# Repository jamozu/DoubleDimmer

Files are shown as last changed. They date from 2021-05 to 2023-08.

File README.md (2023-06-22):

# Introduction
This DIY project is quite involved, so first, why go this route?

There are essentially two ways to control the lights at home, Smart Bulbs or with Smart Light Switches / dimmers, both with advantages and disadvantages. 

Smart Light Switches are cheaper. Purely based on cost, smart light switches are likely to be far cheaper than smart bulbs, especially since one light switch can control multiple light fixtures, depending on how your house’s wiring is set up.

You can use any bulb with Smart Light Switches. Since the traditional light bulb industry is very mature, the range of styles and accessories is still much broader.
Smart Light Switches can control your existing fixtures without complex modifications.

The main disadvantage is that special wiring is required in the electric boxes where the switches are to be installed (the wires for hot, neutral, as well as the wire for the light are required, although there are already some options that do not require both cables, this project has not reached the point of having a single wire power supply). In most recent installations, this is not an issue, but it can be a problem for older installations; also, there are different standards in each country.

While smart bulbs offer more flexibility and have the possibility of adding color, they are more expensive and the need for this level of control, from my point of view, only makes sense in a few specific areas and in the end, you can combine the two solutions.

For these reasons, I leaned towards Smart Light Switches for the bulk of my lights.

Now since there are several options on the market, why go the DIY path?

Mainly I return to the point of the range of styles and accessories. In the arena of traditional light switches, there are thousands of colors, styles, textures and accessory options that are not yet available in smart switches. I started this project a few years ago when smart devices were a lot more expensive.

On the other hand, inexpensive smart switches do not offer enough functionality, and some of the more expensive ones did not fit the form factor of my installation. 

By taking the DIY path, I can get the flexibility in style, form factor, and functionality at a reasonable cost.

With that out of the way, let’s go to the project itself.

# IoT Double Dimmer

This project consists of an AC light dimmer for one or two incandescent light bulbs or dimmable LED bulbs, with mains AC voltage of 110 to 220 V, 50 or 60Hz, up to 400W, using the WiFi enabled microcontroller ESP-12E / F.

The Dimmer functionality is achieved using the phase control method, using a TRIAC for each bulb, varying the total power applied. This method works very well with incandescent light bulbs and with LED lamps that have the Dimmable specification.

Features:
* Lights can be dimmed from 5% to 100% power.
* The minimum power is configurable for different types of bulbs and environments.
*	Supports transitions between brightness levels.
*	One push button per light bulb to control the ON/OFF state and brightness.
*	A LED indicator for each button/light bulb.
*	LED indicators change intensity if light is ON or OFF. 
*	LED indicators intensity can be set remotely or turned off for day / night mode.
*	Smart control and configuration using MQTT over WiFi; An MQTT broker is required.
*	ON/OFF state and brightness can be set via the push buttons or remotely via WiFi/MQTT.
*	Integrated into Home-Assistant or other MQTT compatible IoT Hubs, with auto discovery.
*	Setup Portal over WiFi, to configure WiFi/MQTT parameters.
*	The Setup Portal is started by a double reset or optionally with multi-click of any of the light buttons.
*	On Power Up the device resets to the last known state, using MQTT retain or EEPROM.
*	Optional double and triple clicks to trigger additional actions.
*	Advanced configuration through MQTT.
*	Each light can be set to "Switch Mode" in case the Dimmer functionality is not required or supported in a specific bulb.
*	The Dimmer auto detects AC frequency.

For mor details check the documentation at: https://github.com/jamozu/DoubleDimmer/blob/main/RRoble_Double_Dimmer.pdf

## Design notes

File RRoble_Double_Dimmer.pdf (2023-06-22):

# RRoble Double Dimmer

## Single and Double Dimmer with IoT over WiFi

Revision History
Version date | Author | Change Summary
Tuesday, June 25, 2019 | Jesus Amozurrutia | First Draft
Saturday, November 07, 2020Jesus Amozurrutia | | Version 1
Friday, April 30, 2021 | Jesus Amozurrutia | Version 2
Monday, November 01, 2021 Jesus Amozurrutia | | Version 3
Tuesday, January 31, 2023 | Jesus Amozurrutia | Version 4
Thursday, June 22, 2023 | Jesus Amozurrutia | Version 5

Confidential | Page 2

Contents

## 1. Introduction

This DIY project is quite involved, so first, why go this route?
There are essentially two ways to control the lights at home, Smart Bulbs or with Smart Light Switches / dimmers, both with advantages and disadvantages.
Smart Light Switches are cheaper. Purely based on cost, smart light switches are likely to be far cheaper than smart bulbs, especially since one light switch can control multiple light fixtures, depending on how your house’s wiring is set up.
You can use any bulb with Smart Light Switches. Since the traditional light bulb industry is very mature, the range of styles and accessories is much broader. In recent years, new smart lights solutions have appeared that allow for flexibility and different styles, but for the bulk of the lights it is a home or office, the Smart Switch is still the best option.
Smart Light Switches can control your existing fixtures without complex modifications.
The main disadvantage is that special wiring is required in the electric boxes where the switches are to be installed (the wires for hot, neutral, as well as the wire for the light are required, although there are already some options that do not require both cables, this project has not reached the point of having a single wire power supply). In most recent installations, this is not an issue, but it can be a problem for older installations; also, there are different standards in each country.
While smart bulbs offer more flexibility and have the possibility of adding color, they are more expensive and the need for this level of control, from my point of view, only makes sense in a few specific areas and in the end, you can combine the two solutions.
For these reasons, I leaned towards Smart Light Switches for the bulk of my lights.
Now since there are several options on the market, why go the DIY path?
Mainly I return to the point of the range of styles and accessories. In the arena of traditional light switches, there are thousands of colors, styles, textures and accessory options that are not yet available in smart switches. I started this project a few years ago when smart devices were a lot more expensive.
On the other hand, inexpensive smart switches do not offer enough functionality, and some of the more expensive ones did not fit the form factor of my installation. I have also had the experience that my visitors who are not familiar with devices find some of these devices unintuitive.
By taking the DIY path, I can get the flexibility in style, form factor, and functionality at a reasonable cost.
With that out of the way, let’s go to the project itself.

## 2. IoT Double Dimmer

This project consists of an AC light dimmer for one or two incandescent light bulbs or dimmable LED bulbs, with mains AC voltage of 110 to 220 V, 50 or 60Hz, up to 400W, using the WiFi enabled microcontroller ESP-12E / F.

The Dimmer functionality is achieved with the phase control method, using a TRIAC for each bulb, varying the total power applied. This method works very well with incandescent light bulbs and with LED lamps that have the Dimmable specification.
Features:
- Lights can be dimmed from 5% to 100% power.
- Supports transitions between brightness levels.
- One push button per light bulb to control the ON/OFF state and brightness.
- Single click toggles ON/OFF state.
- Continues press changes brightness.
- A LED indicator for each button/light bulb.
- LED indicators change intensity if light is ON or OFF.
- LED indicators intensity can be set remotely or turned off for day / night mode.
- ON/OFF state and brightness can be set via the push buttons or remotely via WiFi/MQTT.
- Smart control and configuration using MQTT over WiFi; An MQTT broker is required.
- Setup Portal over WiFi, to configure WiFi/MQTT parameters.
- The Setup Portal is started by a double reset or optionally with multi-click of any of the light buttons.
- On Power Up the device resets to the last known state, using MQTT retain or EEPROM.
- Optional double/triple clicks to trigger additional actions.
- Integrated into Home- (https://www.home-assistant.io/)Assistant (https://www.home-assistant.io/) or other MQTT compatible IoT Hubs, with auto discovery.
- Advanced configuration through MQTT.
- Dimming time.
- Default transition speed.
- Minimum power can be set for each light.
- Minimum Turn ON Brightness (some cheap LED bulbs require some a minimum brightness level to actually turn ON).
- Each light can be set to "Switch Mode" in case the Dimmer functionality is not required or supported.
- The Dimmer auto detects AC frequency.

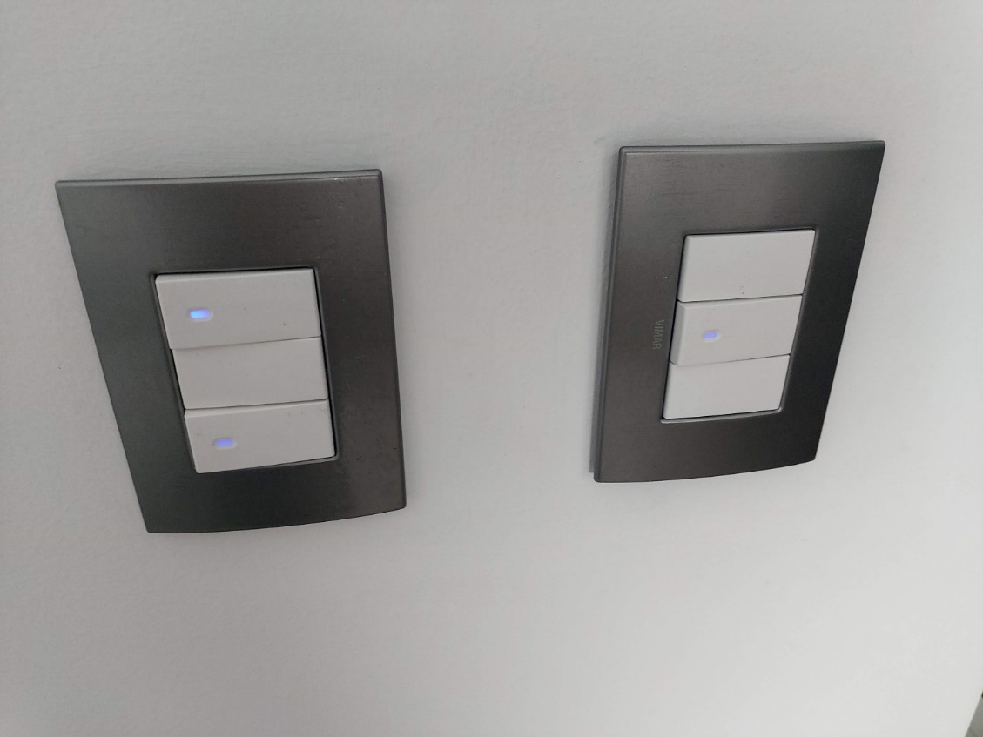
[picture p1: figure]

The finished product.

## 2.1. Definitions

- Device: Refers to the component as a whole. It is used to identify the status and to set the configuration.
- Instance: It refers to each of the lights. The status and configuration of each of the instances can be set individually.
- Brightness: Relative brightness for each of the light bulbs. Brightness is scaled from 1, for minimum brightness, to 100, for maximum brightness.
- Zero Crossing is a pulse that detects every time the AC sinusoidal electrical voltage signal crosses the zero volt zone. It is used to synchronize the phase control.
- Power: The electrical power applied to the light bulb to achieve the desired brightness. Power is regulated using phase control, by varying the time to trigger the TRIAC after the zero crossing detection. The applied power is linear and proportional to the brightness value.
- Minimum Power: The minimum power applied to the light bulb when the brightness has a value of 1. The default value is 5% and it can be configured to any value between 4% and 50%.
- Duty Cycle: The time that the TRIAC is ON in relation to the duration of the AC power signal period.
- OTA: Over The Air updates. Allow the firmware to be updated over WiFi.

## 3. Hardware

The hardware is based on an ESP-12E/F micro controller, using TRIACs to control the power applied to the light bulbs. The controller board is mounted over some Vimar® wall switches. I choose this particular brand because it features a wide range of styles and colors for the decorative plates and buttons. Finally, a 3D printed cover to protect the circuit.
The parts I am using from Vimar® are:

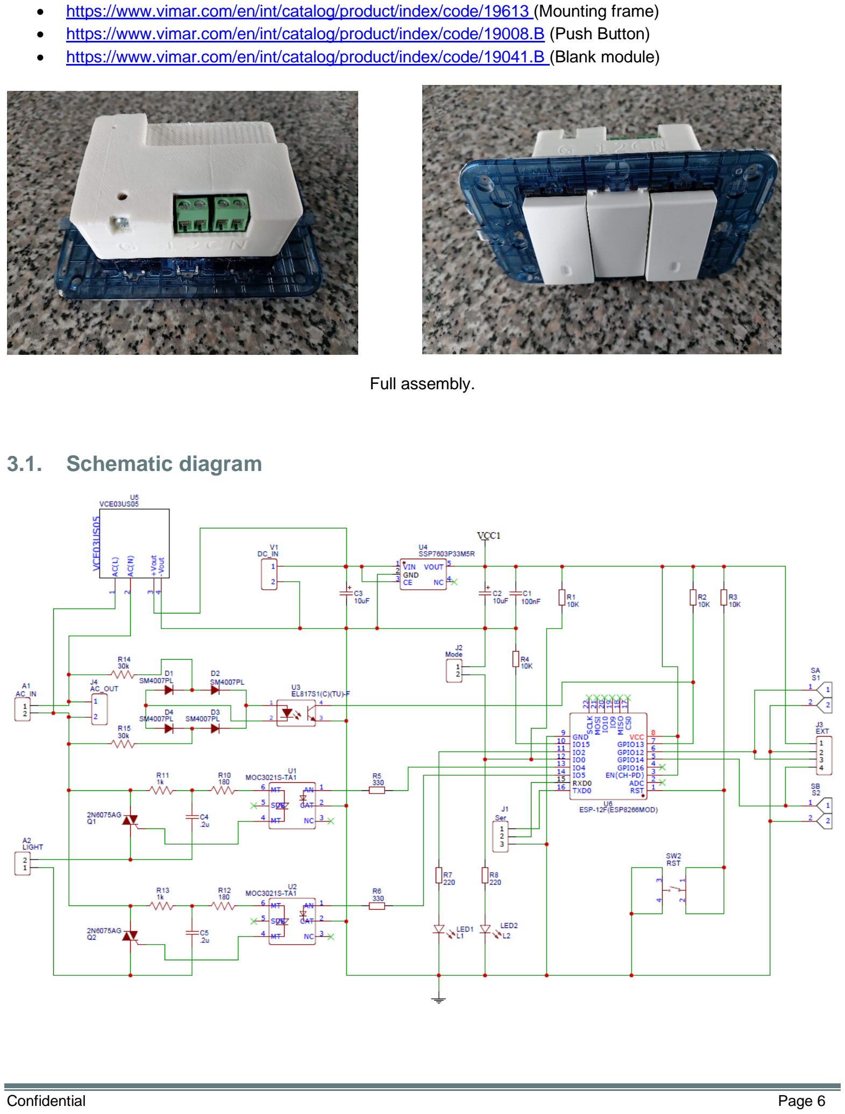
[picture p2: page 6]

- https://www.vimar.com/en/int/catalog/product/index/code/19613 (Mounting frame)
- https://www.vimar.com/en/int/catalog/product/index/code/19008.B (Push Button)
- https://www.vimar.com/en/int/catalog/product/index/code/19041.B (Blank module)

Full assembly.

## 3.1. Schematic diagram

## 3.2. PCB

The latest version of the PCB is based on surface mount components, to minimize board dimensions.

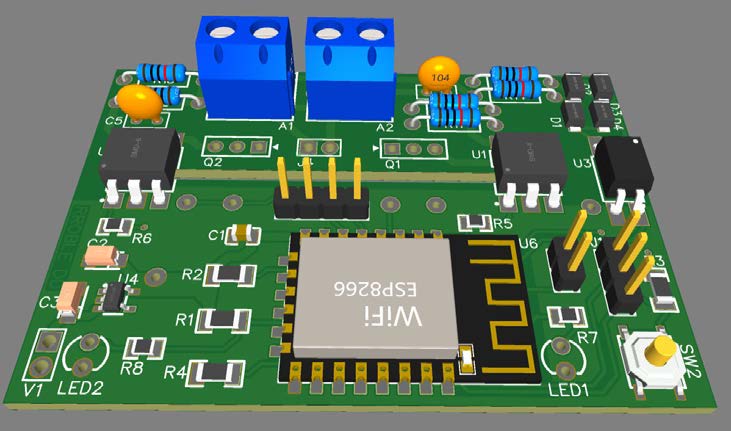
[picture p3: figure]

PCB with components (Missing TRIACs and LEDs).

The details of the PCB are available here:
https://oshwlab.com/jamozu/multi_project_copy_copy_copy_copy_copy
I have used JLC's services to manufacture the PCBS and they also offer assembly service for surface mount components.

## 3.3. Bill of material

ID | Designator | Quantity | Name | Description | LCSC Assembly
2 | A1, A2 | 1 | TERM | Screw terminal
3 | C1 | 1 | 100nF | Capacitor | Yes
4 | C2,C3 | 2 | 10uF | Electrolytic capacitor | Yes
5 | C4,C5 | 2 | .2u | Capacitor
6 | D1,D2,D3,D4 | 4 | SM4007PL | Diode | Yes
7 | J1 | 1 | 3 Pin Header | 2.5 mm Header
8 | J2 | 1 | 2 Pin Header | 2.5 mm Header
9 | J3 | 1 | 4 Pin Header | 2.5 mm Header
10 | J4 | 1 | 2 Pin Header | 2.5 mm Header
11 | LED1 | 1 | 5mm LED | LED
12 | LED2 | 1 | 5mm LED | LED
13 | Q1,Q2 | 2 | 2N6075AG | TRIAC

14 | R1,R2,R3,R4 | 4 | 10K Ohm Resistor | SMT Resitor | Yes
15 | R5,R6 | 2 | 330 Ohm Resistor | SMT Resitor | Yes
16 | R7,R8 | 2 | 220 Ohm Resistor | SMT Resitor | Yes
17 | R10,R12 | 2 | 180 Ohm Resistor | Resitor 1/2 W
18 | R11,R13 | 2 | 1K Ohm Resistor | Resitor 1/2 W
19 | R14,R15 | 2 | 30K Ohm Resistor | Resitor 1/2 W
20 | SA | 1 | 19008.B | Vimar Push Button
21 | SB | 1 | 19008.B | Vimar Push Button
22 | SW2 | 1 | RST | Push Button | Yes
23 | U1,U2 | 2 | MOC3021S-TA1 | TRIAC Opto-cupler | Yes
24 | U3 | 1 | EL817S1(C)(TU)-F | Opto transistor | Yes
25 | U4 | 1 | SSP7603P33M5R | 3.3V Voltage regulator | Yes
26 | U5 | 1 | VCE03US05 | 5V AC-DC converter
27 | U6 | 1 | ESP-12F(ESP8266MOD) | ESP Microcontroller

## 3.4. Assembly

The PCB is installed over the Vimar® pushbuttons. The pushbuttons have a hole for the LED indicators and the cable clips are used to hold the button pins. The second cable clip for each pushbutton connects to the ground of the 5V power supply.

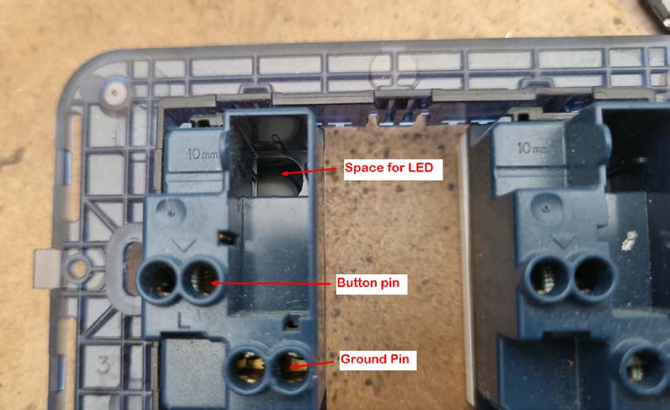
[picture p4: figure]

Push button assembly details. On the back, the PCB has the LEDs and button pins, as well as the AC cables for the 5V power supply.

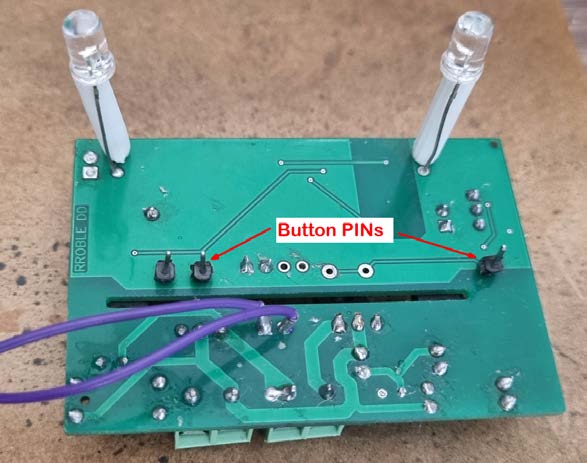
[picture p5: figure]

The 5V power supply is installed in the space between the pushbuttons.

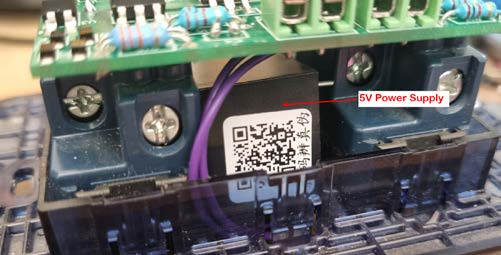
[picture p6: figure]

The LEDs and button pins are inserted into the corresponding slots on the push button and the push button screw is tightened once the board is flush with the push button. For best results you can use a little conductive paste in the cable clips.

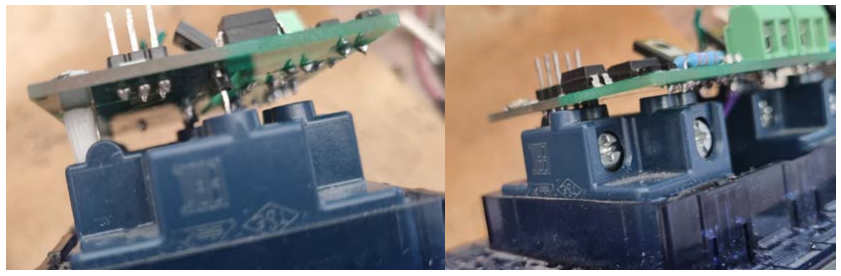
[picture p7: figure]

## 4. Flashing Software

Once the hardware is assembled and before placing the cover, it is necessary to flash the software for the first time. To connect the device with the computer an FTDI configured for 3.3V is required. Connect the PC via USB with a 3.3V FTDI adapter with jumper cables. Only 3 pins are used; TX0, RX0 and GND. Set a jumper in J2.

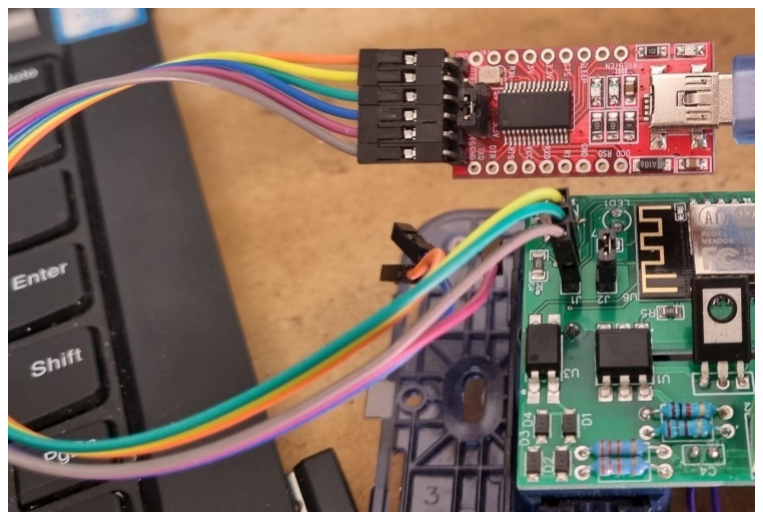
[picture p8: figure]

To power the device, you can connect 5V across V1 or 3.3V on pins 1 and 2 of J3. It is not recommended to flash by connecting to the mains power, due to the risk of electric shock or damage to the PC.
Open Arduino IDE and open the “DimmerEsp_Current.ino” sketch.
Under the Tools menu, set the Board to “Generic ESP8266 Module” and the set the following parameters for the board:

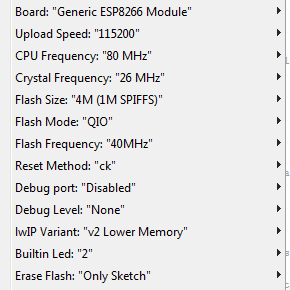
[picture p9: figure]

The file system (SPIFFS) is required to save configuration parameters.
Open the Serial Monitor to make sure that there is communication between the computer and the device and that it boots in the correct mode:

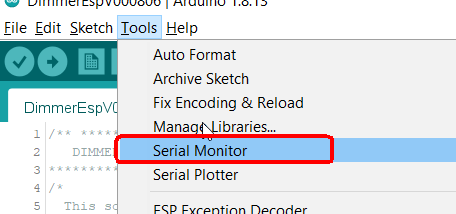
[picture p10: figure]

Configure the serial monitor to a baud rat of 74880.
Apply power to the device, then the ESP will boot on flash mode (1). You should see something like this in the serial monitor:

ets Jan 8 2021,rst cause 1, boot mode:(1,2)

At this point the J2 jumper can be removed.
Click the upload button on the Arduino IDE to start flashing.

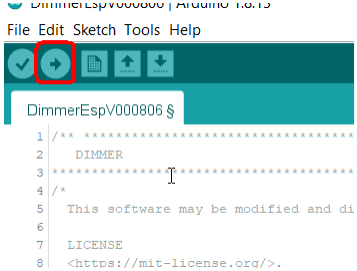
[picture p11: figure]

The device is ready to operate. Remove the jumper from J2 if it is still in place and put the cover; now it can be connected to the mains power and lights through the screw terminals.

## 5. Installation

Install the dimmer according to the diagram:

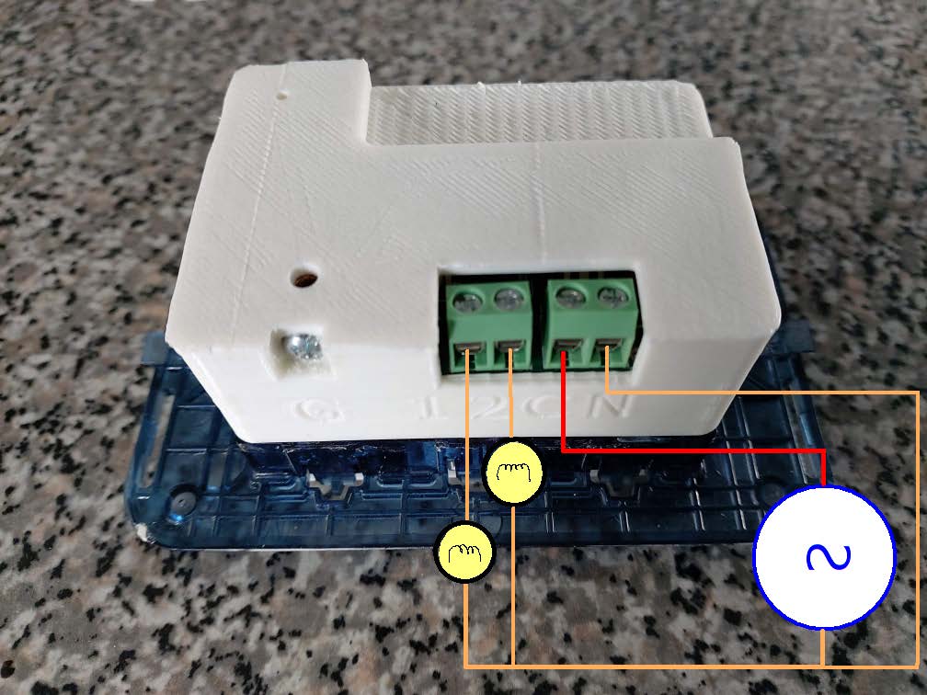
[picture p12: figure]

## 6. Setup portal

Once the device is connected, you can configure the parameters of the WiFi network with the Setup Portal. To activate the Setup Portal:
- If it is not already screwed into the wall, a double reset can be done on the back of the device;
- Otherwise you can activate the portal by doing 6 to 8 clicks on any of the buttons within 4 seconds.
The device indicators start flashing every second. On a computer or mobile device, search for a WiFi network with a name like “RDimmer_XXXXXXXXXXXX” and select it.
Open a browser. It should automatically direct you to the Setup Portal. In case the portal does not open, you can go to the address “http://192.168.4.1/“ to open it manually.
Follow the on-screen instructions to set the WiFi configuration and MQTT parameters.
For more information on the Setup Portal see: https://github.com/tzapu/WiFiManager

## 7. Advanced Configuration

Various device parameters can be configured remotely using MQTT commands.

## 7.1. Home Assistant

If the Broker that was configured with the Setup Portal is part of Home Assistant or other MQTT compatible hubs, the device should work out of the box. By default, auto-discovery is enabled, so Home Assistant (https://www.home-assistant.io/) should discover the dimmer as soon as the initial configuration is done.

## 7.2. Configuration

Various parameters can be configured through MQTT commands. Those commands can be sent using any MQTT program, for example mosquitto that comes as part of Home Assistant installation with MQTT. To run mosquitto you can use the SSH add-on.
For example for a device called “bedroom” in the namespace “MyHome” we can change the minimum power applied to the light bulbs (We have found this may be necessary with some LED lamps that do not turn on at low power levels):

mosquitto_pub -h my.broker.net -p 1883 -t "MyHome/light/bedroom/set" -m '{"action":"config", "secret":"secret", "minPow1":10, "minPow2":10}' -u USER -P PASS
- Set the second light to Switch mode:

mosquitto_pub -h my.broker.net -p 1883 -t "MyHome/light/bedroom/set" -m '{"action":"config", "secret":"secret", "LgtDimm2":false}' -u USER -P PASS
- Set the name for both lights:

mosquitto_pub -h my.broker.net -p 1883 -t "MyHome/light/bedroom/set" -m '{"action":"config", "secret":"secret", "name1":"bedroom_left", "name2":"bedroom_right"}' -u USER -P PASS
The parameters that can be configured using MQTT are:
Parameter | Type | Description | Values | Default
myId | string [20] | Device ID. | [a-z0-9_.] | MAC Address
retain | bool | MQTT Retain flag. If this flag is set, the last known state for the light is preserved by the MQTT broker. | TRUE = On; FALSE = Off | TRUE
keepAlive | int | MQTT Keep alive in seconds. | 60 – 10000 | Default [59]
dimmTime | int | Time to go from 0% brightness to 100% brightness or vice versa (milliseconds) | 500 - 20000 | 2500
edgeTime | int | Delay at the edge of the dimmable range in milliseconds (makes it easy to select the Minimum or Maximum brightness). | 100 – 3000 | 800

LedInstOn | int | LED indicator intensity when the lights are ON. | 0 – 100 | 100
LedInstOff | int | LED indicator intensity when the lights are OFF. | 0 - 100 | 25
LedDefault | bool | Default state for LED Indicators. | TRUE = On; FALSE = Off | TRUE
transitionOn | int | Transitions speed to turn ON with the button, in seconds. | 0 – 12 | 0
transitionOff | int | Transitions speed to turn OFF with the button, in seconds. | 0 – 12 | 0
name1 | string [40] | Name of first light. It must be unique inside the MQTT namespace. If the name is not defined, it uses an auto generated INSTANCE_ID based on the MAC address. | [a-z_0-9] | “”
name2 | string [40] | Name of second light. It must be unique inside the MQTT namespace. If the name is not defined, it uses an auto generated INSTANCE_ID based on the MAC address. | [a-z_0-9] | “”
LgtDimm1 | bool | Light 1 mode. | TRUE = Dimmer; FALSE = Switch | TRUE
LgtDimm2 | bool | Light 2 mode. | TRUE = Dimmer; FALSE = Switch | TRUE
LgtTrns1 | bool | Light 1 transition. Enables the fade effect. | TRUE = Enabled; FALSE = Disabled | TRUE
LgtTrns2 | bool | Light 2 transition. Enables the fade effect. | TRUE = Enabled; FALSE = Disabled | TRUE
brightness1 | int | Default brightness for Light 1. | 1 – 100 | 100
brightness2 | int | Default brightness for Light 2. | 1 – 100 | 100
minPow1 | int | Minimum Power % for Light 1. | 4 – 50 | 10
minPow2 | int | Minimum Power % for Light 2. | 4 – 50 | 10
minTUB1 | int | Minimum Turn ON brightness for Light 1. It is used for some LED bulbs that do not turn on at low power levels. | 0 – 50 | 0
minTUB2 | int | Minimum Turn ON brightness for Light 2. | 0 – 50 | 0

## 8. Software

The hardware is compatible with libraries such as ESPHome, (https://esphome.io/) using the AC Dimmer (https://esphome.io/components/output/ac_dimmer.html) component, but this is out of the scope of this document.
For this project, I decided to create my own software to have more granular control of the features, which is what is described below.
If you have already reached this point, your can have a working dimmer. This section is part of the software's internal documentation. If you want to know more details and how you can improve the project, continue with this section. The software is developed in C++ with the Arduino® platform.

## 8.1. Dimmer

The dimmer function as follows:
- A single button controls the State and brightness of each light bulb.
- Short press = Toggle State ON/OFF.
- Long press = Change brightness from 100% to 0% and back, while the button remains pressed.
- Button release after a Long Press = Sets the brightness and calculates the powe/duty-cycle.
- Double click and triple click can be enabled to trigger an MQTT action that can be used for any additional function using the MQTT hub.
- If the light State is OFF, the signal to trigger the TRIACs stays down.
- If the light State is ON, the ESP waits for the Zero Crossing Pulse (ZCP) signal and triggers the TRIAC according to the current duty cycle.
- The minimum power level that can be applied to any Light is 5%. The minimum power can be adjusted for each Light through MQTT configuration.
- Brightness value can be set between 1 and 100: 100 = Maximum brightness; 1 = Minimum brightness, where 1 corresponds to the minimum power and 100 to 100% power.
- The duty-cycle is calculated so that the total power has a linear relation with the brightness level.
- The dimmer can be configured as a switch. In this case the TRIAC only turns ON or OFF.
- The sketch can be compiled in Switch Mode. In this mode, the dimmer functions are disabled, and the operation of the LED indicators changes to reflect which instance is ON. See SWITCH_MODE and HIGH_IMPEDANCE on the sketch.
The zero-crossing pulse (ZCP) is connected to a pin on the ESP that handles hardware interrupts.
On power up, the device detects the AC power frequency and the duration (width) of the ZCP. Once the AC parameters are obtained, the device enters normal operation mode.
In normal operation mode, the ESP gets a hardware interruption in the rise part of the ZCP. At this point, if the light is ON, it sets the timer interruptions used to trigger the TRIAC(s) based on the current duty-cycle.
If one or both lights are turned on, up to 4 timers can be defined:
1) Trigger first TRIAC. This can trigger Light 1 and/or Light 2. If both lights have the same duty-cycle they will trigger at the same time.
2) Trigger second TRIAC. (conditional) This can trigger Light 1 and/or 2. If the lights have a different duty-cycle values the light with the lower duty-cycle is triggered with the second timer.

3) Turn Off trigger signal. At 95% of the time before the next ZCP, the trigger signal for the TRIACs is turned off.
4) Repeat cycle at step 1. The last timer is the time between the Turn Off trigger signal and the trigger of the next cycle. This timer is overridden by the next ZCP interrupt, but in case the pulse is not detected, the cycle is repeated anyway; this prevents light flickering in case of AC noise.
The timers use ESP’s timer_1 interrupt and are triggered in sequence using a single hardware timer.
The following graph shows the operation of a double dimer, with a light on at 95% power and the second light on at 27% power.
You can see the ZCP signal, the calculated timers, the signals to trigger the TRIACs and the power applied to the light bulbs.

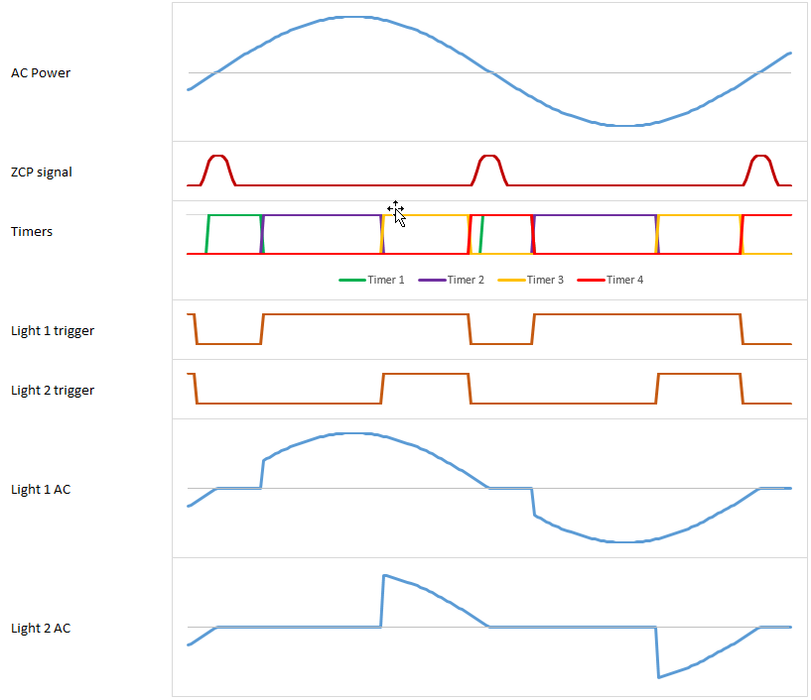
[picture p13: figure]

The program loop takes care of the rest of the tasks like:

- Detects the button status and sets the ON/OFF/Duty-cycle of each light.
- Sets the indicator LEDs brightness.
- Monitor WiFi connectivity.
- Schedule MQTT out messages.
The incoming MQTT messages are handled by a callback function of the MQTT library.

## 8.2. WiFi

The ESP microcontroller communicates with an MQTT broker, using WiFi in normal operation mode; in this case the device is a client in an existing WiFi network.
The device can be set for the initial configuration mode; in this case, the device uses WiFi in access point mode and an internal web server catches the requests for initial configuration.

### 8.2.1. MQTT Topics

The Dimmer uses 2 or 3 MQTT topics for publishing:
1) Device state:

## NAMESPACE/light/DEVICE_ID/state

2 & 3) Status of each Light:

## NAMESPACE/light/INSTANCE_ID/state

It also subscribes to 2 or 3 MQTT topics:
1) Configure the device:

## NAMESPACE/light/DEVICE_ID/set

2 & 3) Set the light status or request feedback:

## NAMESPACE/light/INSTANCE_ID/set

The NAMESPACE can be configured on the WiFi setup portal or trough MQTT The DEVICE_ID is set using the MAC Address in the form: XXXXXXXXXXXX. INSTANCE_IDs are defined as:

- NXXXXXXXXXXXX1
- NXXXXXXXXXXXX2
The Instance ID can be overridden using the configuration parameters "name1" and "name2".

### 8.2.2. MQTT Messages

The Dimmer publishes the following messages:

## - NAMESPACE/light/DEVICE_ID/state

- {"state":“golive”} → This message is published after the device is turned on, or after a reset. This is can be used to obtain the last known state in the IoT Hub after a reset or power outage
- {" state ":"online"} → Published periodically every KEEPALIVE seconds.
- {" state ":"reset"} → Published before the device resets.
- {"feedback":"configuration saved"} → Published after a configuration change is saved.

## - NAMESPACE/light/INSTANCE_ID/state

- {"state":["ON"|"OFF"], "brightness":[0-100], "power":[0-100], "indicator":["ON"|"OFF"]} The dimmer is constantly listening on the feedback topics and it accepts the following messages:

## - NAMESPACE/light/DEVICE_ID/set

- {"action":"config",
"secret":CONFIG_SECRET,
"mqttbroker":MQTT_BROKER_NAME-IP, "mqttport":MQTT_PORT,
"mqttuser":MQTT_USER,
"mqttpass":MQTT_PASSWD,
"namespc":MQTT_NAME_SPACE, "mqttdisc":MQTT_AUTO_DISCOVERY, "mqttkey":MQTT_SHARED_KEY, "keepAlive":KEEP_ALIVE_SECONDS}
- {"action":"config",
"secret":CONFIG_SECRET,
"LgtMode":BOOL,
"LgtDimm1":BOOL,
"LgtTrns1":BOOL,
"LgtDimm2":BOOL,
"LgtTrns2":BOOL,
"LedBright":INT,
"LedDimm":INT,
"dimmTime":INT,
"edgeSpeed":INT,
"transitionOn":INT,
"transitionOff":INT,
"name1":LIGHT1_NAME,
"name2":LIGHT2_NAME,
"minPow1":LIGHT1_NAME,
"minPow 2":LIGHT2_NAME,
"brightness1":LIGHT1_NAME, "brightness2":LIGHT2_NAME}
- {"action":"getStatus","instance":NUMBER}
- {"action":"indicators","bright":NUMBER,"dimm":NUMBER}
- {"action":"reset"}

## - NAMESPACE/light/INSTANCE_ID/set

- {"state":["ON"|"OFF"],"brightness":[0-100],"transition":[0-10],"indicator":["ON"|"OFF"]}

- {"action":"getState"}
- {"action":"getConfig"}

### 8.2.3. Configuration

The device can be configured trough the WiFi Portal and through MQTT messages.
WiFi Portal
The portal is used for the initial device configuration. It allows to configure the SSID and Key of the WiFi network, as well as the MQTT broker and optionally the IDs for each light.
To enter the configuration mode, you need physical access to the reset button on the back of the Dimmer or do a multiple click (6 clicks within 4 seconds).
A Wi-Fi-enabled device, such as a phone, tablet or computer, is also required.
To enter the configuration, perform a double reset; press the reset button and wait a second and press a second time, or do a multi-click. The LED Indicators start flashing once per second.
Open the WiFi configuration on the device and look for an SSID called something like "RDimmer_XXXXXXXXXXXX", connect to the network and then point the browser to “http://192.168.4.1/”
Follow the on screen instructions.
MQTT Testing
- Turn On the Living Room light at 50% brightness:

mosquitto_pub -h my.broker.net -p 1883 -t " MyHome/light/living_room/set" -m '{"state":"ON", "brightness":50}' -u USER -P PASS

## 8.3. Home Assistant

By default, auto-discovery is enabled, so Home Assistant (https://www.home-assistant.io/) should discover the dimmer as soon as the initial configuration is done.
It is possible to configure the light manually as described below.

### 8.3.1. configuration.yaml

The parameters for the configuration YAML file are:

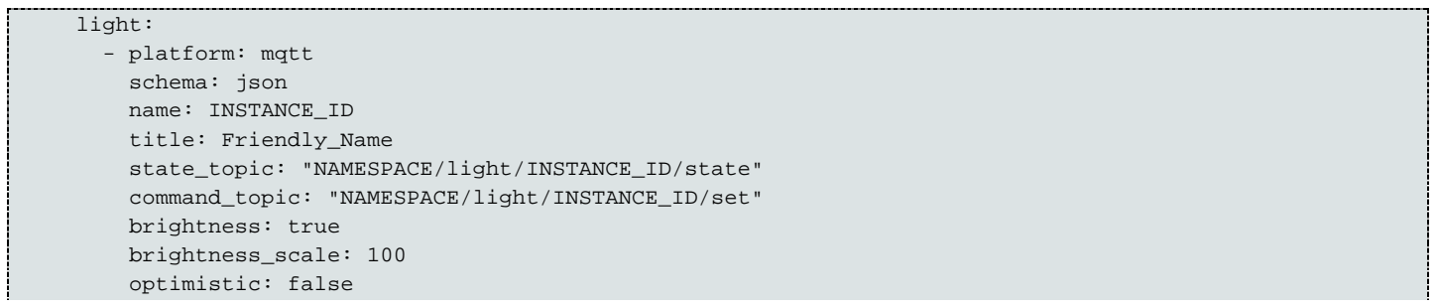
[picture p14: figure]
light: - platform: mqtt schema: json name: INSTANCE_ID title: Friendly_Name; brightness: true brightness_scale: 100 optimistic: false

state_topic: "NAMESPACE/light/INSTANCE_ID/state" command_topic: "NAMESPACE/light/INSTANCE_ID/set"

qos: 0

### 8.3.2. dashboard.dash

If the installation has the HADashboard, (https://www.home-assistant.io/docs/ecosystem/hadashboard/) the configuration for each light in the dashboard configuration file is:

## 8.4. Persistent status

In the event of a blackout or if the power supply is cut, or after a reset, the dimmer can return to its last known state using one of 2 mechanisms:
- EEPROM: The Dimmer saves each state change in EEPROM and retrieves it on boot. See PERSISTENT_STATE parameter in the sketch configuration.
- Retain Flag: By using the "retain" flag on MQTT messages, the dimmer saves its last state in the broker. The MQTT broker must be configured to accept retained messages.
The device can follow one of the following go live sequences, depending on the retain configuration:
- EEPROM: If "PERSISTENT_STATE" is defined and the "retain" parameter is turned OFF (set to FALSE), on power up or after a reset the device enters the "Go Live" sequence:
a. The device reads the last known state from EEPROM.
b. Start dimming.
c. Connects to WiFi.
d. Connects to the MQTT Broker.
e. Publishes a "golive" message on the device's "Sate Topic" (NAMESPACE/INSTANCE_TYPE/DEVICE_ID/state).
This can be optionally used by the Broker or Hub to override the initial state.
f. Subscribes to the "Instance Set" topics (NAMESPACE/INSTANCE_TYPE/INSTANCE_ID/set) and listens for commands.
g. Continues normal operation.
Any state change is published to the "Instance State" topics with the retain flag turned OFF.
- Retain: If the "retain" parameter is turned ON (set to TRUE), on power up or after a reset the device enters a different "Go Live" sequence:
- Start dimming.
- Connects to WiFi.
- Connects to the MQTT Broker.
- Subscribes to the "Instance State" topics
(NAMESPACE/INSTANCE_TYPE/INSTANCE_ID/state).
- The broker sends the last known state back to the Device, per MQTT standards with retain.
- After getting the last known state from the broker for all instances the dimmer, or if the initial state is not received after 60 seconds (see GO_LIVE_DURATION), the device un-subscribes from the "Instance State" topics.
- Subscribes to the "Instance Set" topics (NAMESPACE/INSTANCE_TYPE/INSTANCE_ID/set)

- Continues normal operation.
Any state change is published to the "Instance State" topics with the retain flag turned ON.

If WiFi or the MQTT Broker are not available during power up, the device will resume normal operation after 60 seconds. Also, if the user sets the status manually before the device can reach the MQTT broker, the "Go Live" sequence is canceled.
With this method the dimmer can establish its initial state with an MQTT broker using the retain standard and without additional functionality required by the Hub.
If Home Assistant (HA) is used, this method is preferred as it reduces the risk of HA and the dimmer being out of sync. In the event of temporary network failures or rebooting of any of the involved devices.
Any user activity, like pressing a button cancels the "Go Live" sequences.

## 8.5. OTA Update

This sketch supports OTA updates for development purposes, using the Arduino IDE or an HTTP server. Currently, HTTP updates only support unsecured http, therefore it is only recommended in a local environment for development purposes.
It is possible to implement secure https, as in the next example, if a public deployment is required: https://gist.github.com/igrr/24dd2138e9c8a7daa1b4, but at the moment it is out of scope.

Note: Temporarily disable the firewall in the computer while uploading a new image to the controller, to avoid disconnection problems when using OTA with the Arduino IDE.

## 8.6. Libraries

The software uses the following libraries:
- ESP8266 core for Arduino (https://github.com/esp8266/Arduino).
- ESP8266 WiFi Connection manager (https://github.com/tzapu/WiFiManager).
- Double Reset Detect (https://github.com/jenscski/DoubleResetDetect).
- Arduino Json (https://github.com/bblanchon/ArduinoJson/)
- Asynchronous MQTT Client (https://github.com/marvinroger/async-mqtt-client/releases/tag/v0.8.1).

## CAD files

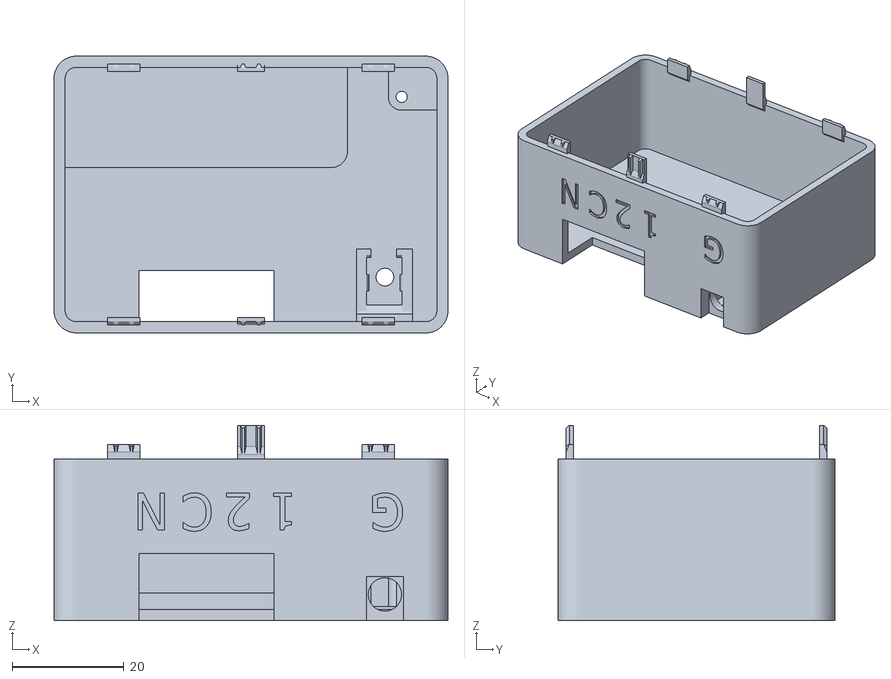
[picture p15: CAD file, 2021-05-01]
hardware/Double_Dimmer_Cover.stl
70.6 x 49.6 x 35.0

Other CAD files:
hardware/Single_Dimmer_Cover.stl

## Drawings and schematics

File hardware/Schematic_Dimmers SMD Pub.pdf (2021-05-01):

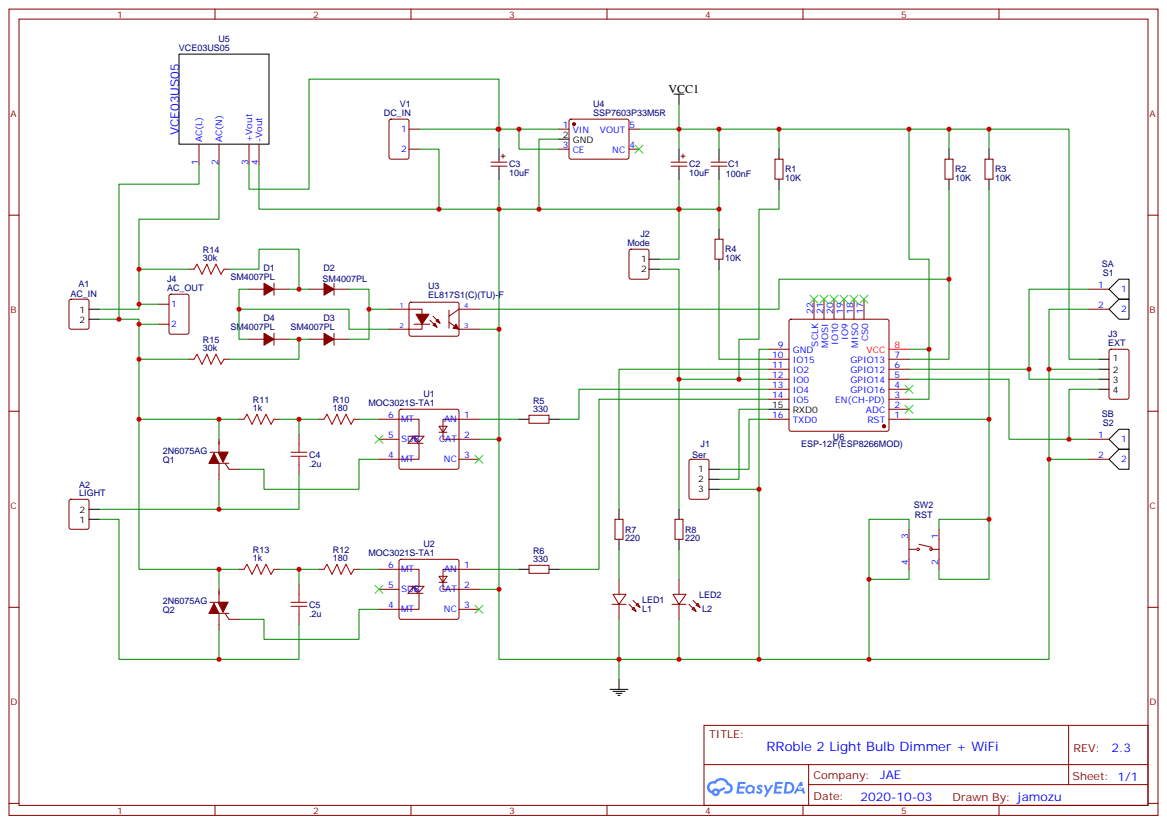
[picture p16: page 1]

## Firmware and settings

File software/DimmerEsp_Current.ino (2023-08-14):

/** **********************************************************************************************
   DIMMER
*********************************************************************************************** */
/*
  This software may be modified and distributed under the terms of the MIT license.

  LICENSE
  <https://mit-license.org/>.
  ------------------------------------------------------------------------------------------------
  Copyright © 2023 Jesus Amozurrutia
  
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
  ------------------------------------------------------------------------------------------------
  RRoble Double Dimmer
  ------------------------------------------------------------------------------------------------
  
  This project consists of an AC light dimmer for one or two incandescent light bulbs or dimmable 
  LED bulbs, with AC of 110 to 220 volts, 50 or 60Hz, using the WiFi enabled controller ESP-12E.
  
  The Dimmer function is achieved using the phase control method, using a TRIAC for each bulb, 
  varying the total power applied. This method works very well with incandescent light bulbs and 
  with LED lamps that have the Dimmable specification.
  
  Features:
  - Smart control and configuration using MQTT over WiFi. An MQTT broker is required.
  - One push button per light bulb to control the ON/OFF state and brightness.
  - ON/OFF state and brightness settings can be made via the integrated buttons or remotely via 
    WiFi/MQTT.
  - Lights can be dimmed from 2% to 100% power.
  - Supports transitions between brightness levels.
  - A LED indicator for each button/light bulb.
  - LED indicators change intensity if light is ON or OFF. 
  - LED indicators intensity can be set remotely or turned off for day / night mode.
  - Integrated into Home-Assistant or other MQTT compatible IoT Hubs, with auto discovery.
  - Setup Portal over WiFi, to configure WiFi/MQTT parameters, triggered by a double reset or
    optionally with multi-click on any of the light buttons.
  - On Power Up the device resets to the last known state, using MQTT retain or EEPROM.
  - Optional double click to trigger additional devices.
  - Advanced configuration through MQTT.
  - Each light can be set to "Switch Mode" in case the Dimmer functionality is not required or 
    supported.
  - The sketch can be compiled in Switch Mode. In this mode, no dimmer functions are executed and 
    the operation of the LED indicators changes to reflect which instance is ON. 
    See SWITCH_MODE and HIGH_IMPEDANCE.

  ------------------------------------------------------------------------------------------------
  Definitions
  ------------------------------------------------------------------------------------------------

  - Device: Refers to the component as a whole. It is used to identify the status of the device 
    and to set the configuration.
  - Instance: It refers to each of the lights. The status of each of the instances can be set 
    individually.
  - Brightness: Relative brightness for each of the light bulbs. Brightness is scaled from 0, for
    minimum brightness, to 100, for maximum brightness.
  - Zero Crossing: It is a pulse that detects every time the AC sinusoidal electrical voltage 
    signal crosses the zero volt zone. It is used to synchronize the phase control.
  - Power: The electrical power applied to the light bulb to achieve the desired brightness. Power 
    is regulated using phase control, by varying the time to trigger the TRIAC after the zero 
    crossing detection. The applied power is linear and proportional to the brightness value.
  - Minimum Power: The minimum power applied to the light bulb when the brightness has a value of 
    zero. The default value is 2% and can be configured to any value between 2% and 50%.
  - Duty Cycle: The time that the TRIAC is ON in relation to the duration of the AC period.
  - OTA: Over The Air updates. Allow the firmware to be updated over WiFi.
  
  ------------------------------------------------------------------------------------------------
  Pinout ESP-12E
  ------------------------------------------------------------------------------------------------

                 | RST            TXD0 | 
                 | ADC            RXD0 | 
                 | EN             IO5  |-----> TRIAC2 / TRIAC1
                 | IO16           IO4  |-----> TRIAC1
  Button 2 ----->| IO14           IO0  |-----> LED2 
  Button 1 ----->| IO12           IO2  |-----> LED1 
  ZCP      ----->| IO13           IO15 |
                 | VCC            GND  | 

  ------------------------------------------------------------------------------------------------
  EEPROM Map
  ------------------------------------------------------------------------------------------------
  
  000 - 009       Initialization values.
  010 - 029       AC Configuration.
  030 - 109       Instance state.
  110 - 255       Boot information.
  
  ------------------------------------------------------------------------------------------------
  Flashing
  ------------------------------------------------------------------------------------------------
  Board: "Generic ESP8266 Module"
  Built in LED: 2
  Upload Speed: 115200
  CPU Frequency: 80 MHz
  Crystal Frequency: 26 MHz
  Flash Size: 4M (1M LittleFS)
  Flash Mode: QIO
  Flash Frequency: 40 MHz
  Reset Method: ck
  Debug Port: Disabled
  Debug Level: None
  IwIP Varaint: v2 Lower Memory
  
  
  ------------------------------------------------------------------------------------------------
  Changes
  ------------------------------------------------------------------------------------------------

  0.8.02
  
  - Change ESP.reset() to ESP.restart(), to prevent a config mode loop.
  - Timeout out of AC setup mode by rebooting
  
  ----------------
  0.8.03
  
  - Save last known AC Freq. and ZC pulse duration to EEPROM.
  - Timeout of AC setup mode with the saved AC setup data.
  - Fix debounce issues with the AC setup, preventing de detection of the ZC pulse with.
  - Implement "Minimum Turn On Brightness" (minTUB).
  - Improve stats collection.
  - Set a verbose/non-verbose mode for reporting system stats.
  - Improved stats collection to include button activity.
  - Fixed a memory overflow issue with debug information.
  - Fix issue with MQTT messages published twice.
  
  ----------------
  0.8.04
  
  - Implement variable frequency.

  ----------------
  0.8.05
  
  - Fix issue with interrupt exception while saving config.
  - Make variable frequency dynamic.
  - Refine "Minimum Turn On Brightness" (minTUB) to include button activity.

  ----------------
  0.8.06

  - Some cleanup
  
  ----------------
  0.8.07

  - Correct MQTT debug information.
  - Isolate Debug variables.
  - Improve WiFi reconnect retry.
  - Smooth variable frequency.
  - Fixed issue with flickering when 2 lights are turned on.

  ----------------
  0.8.08

  - Fix issue with reporting IP address in "getInfo" MQTT event.
  - Change the saved AC Freq read process, to prevent potential infinite boot loop.
  - Improve WiFi/MQTT re-connect sequence.

  
  ------------------------------------------------------------------------------------------------
  Todo
  ------------------------------------------------------------------------------------------------

  Future:
  - MQTT Signatures
  - HTTPS support for image download
  
  ------------------------------------------------------------------------------------------------
  ------------------------------------------------------------------------------------------------
  @author Jesus Amozurrutia Elizalde <jamozu@gmail.com>
  @version 0.8.08
  @date 2023/08/13
  @since Friday February 01 2019, 10:32:00
  @copyright MIT license
  @pre Device: ESP-12E (ESP8266)
*/

//////////////////////////////////////////////////////////////////////////////////////////////////
//////////////////////////////////////////////////////////////////////////////////////////////////
//
// Sketch configuration starts here
//
//              v            v            v            v            v 

/* --------------------------------------------------------------------------------------------
   Device identification
   -------------------------------------------------------------------------------------------- */
// Hardware version
#define HVERSION                          "02"
#define HVERSION_NUM                      2

// Software version
#define SVERSION                          "0.8.08"

// Title for the application
#define DEVICE_TITLE                      "RRoble Dimmer Switch"

// Title for WiFi/MQTT Setup Portal
#define PORTAL_PREFIX                     "RDimmer_"


/* --------------------------------------------------------------------------------------------
   Features
   -------------------------------------------------------------------------------------------- */
// Number of instances [1 - 2]; 3, 4 instances to be implemented for ESP32
#define INSTANCE_NUM                      2

// Enable persistent state in EEPROM. Saves light state to EEPROM (if MQTT Retain flag is OFF)
#define PERSISTENT_STATE

// Enable double/triple click events
#define DBL_CLICK

// Enable multiple clicks to start the Setup Portal
#define MULT_CLICK

// Enable MQTT discovery (compatible with HomeAssistant)
#define MQTT_DISCOVERY

// MQTT configuration enabled. Allows the device to be configured remotely trough MQTT
#define MQTT_CONFIG 

// Allow reset through MQTT message
#define MQTT_RESET

// Enable OTA Updates
#define OTA_UPDATES

// Save staus information on reset (useful for debugging network issues)
#define COLLECT_STATS

// Number of boot cycles stats collected
#define STATS_NUM                         3

// Allow clearing saved status via MQTT message
#define CLEAR_STATS

// Set switch mode. In this mode instances just switch ON/OFF and the ZCP/transitions are not 
// used.
//#define SWITCH_MODE

// Enable high impedance mode to turn of switch (some Relay modules require this.)
//#define HIGH_IMPEDANCE


/* -------------------------------------------------------------------------------------------- 
   Dimmer definitions
   -------------------------------------------------------------------------------------------- */
// Go live sequence max duration (sec)
#define GO_LIVE_DURATION                  60

// Mimimum power applied to lamps (5% is a safe value, but some  LED lamps require between 
//  10% and 15% to be vissible and differentiate clearly from the off state
#define MIN_POW                           4

// Maximum value for Minimum power
#define MAX_MIN_POW                       50

// Maximum transition time (ms) 
#define MAX_DIMM_TIME                     20000

// Minimum transition time (ms)
#define MIN_DIMM_TIME                     500

// Maximum time at the edges of the dimmable range (ms). 
#define MAX_EDGE_TIME                     3000

// Minimum time at the edges of the dimmable range (ms).
#define MIN_EDGE_TIME                     100

// Button debounce timer
#define BTN_DEBOUNCE                      50

// Button long press in ms
#define BTN_LONG_PRESS                    800

// Button double click timer in ms
#define DBL_CLICK_INTERVAL                600

// Number of double clicks to trigger the Setup Portal
#define MULT_CLICK_COUNT                  6

// Transition speed on wakeup (after a power outage or reset)
#define CONFIG_TRANSITION_WAKE            5

// Pin value to turn ON
#define INSTANCE_ON                       HIGH

// Pin value to turn OFF
#define INSTANCE_OFF                      LOW

/* -------------------------------------------------------------------------------------------- 
   Network
   -------------------------------------------------------------------------------------------- */
// WiFi re-connect timer (ms)
#define WIFI_RECONNECT                    4034

// Reboot after N consecutive WiFi connect attemps
#define WIFI_CONNECT_REBOOT               10

// Reboot after WiFi is restated N times without connectivity to the broker
#define WIFI_RESTART_REBOOT               3

// Network re-connect timer (ms)
#define NET_RECONNECT                     2504

// MQTT subscription QOS [0, 1]
#define MQTT_SUB_QOS                      1

// MQTT publish QOS [0, 1]
#define MQTT_PUB_QOS                      1

// MQTT maximum number of unanswered events
#define MQTT_MAX_EVENTS                   5

// MQTT Signature (Not implemented yet)
//#define MQTT_SIGN

// MQTT Buffer size (10 - 90)
#define BUFFER_SIZE                       15

// MQTT Subscription Busy Time Out (ms)
#define MQTT_BUSY_TO                      5000

// MQTT Buffer message timer (ms)
#define MQTT_BUFFER_TMR                   350

// Re-subscribe to MQTT Topics (sec)
#define MQTT_RESUBSCRIBE                  600


/* -------------------------------------------------------------------------------------------- 
   Messages
   -------------------------------------------------------------------------------------------- */
// Alive message
#define MQTT_MSG_ALIVE                    "{\"state\":\"online\"}"

// Go live sequence start message to hub/broker
#define MQTT_MSG_GOLIVE                   "{\"state\":\"golive\"}"

// Go live sequence start message to hub/broker
#define MQTT_MSG_RESET                    "{\"state\":\"reset\"}"

// Configuration saved feedback message
#define MQTT_MSG_SAVE                     "{\"feedback\":\"configuration saved\"}"

// Configuration save failed feedback message
#define MQTT_MSG_SAVE_FAIL                "{\"feedback\":\"configuration not saved\"}"

// System stats cleared feedback message
#define MQTT_MSG_SC                       "{\"feedback\":\"stats cleared\"}"

// System stats NOT cleared feedback message
#define MQTT_MSG_SNC                      "{\"feedback\":\"stats not cleared\"}"

// Configuration secret
#define MQTT_SECRET                       "secret"


/* -------------------------------------------------------------------------------------------- 
   Default configuration values
   -------------------------------------------------------------------------------------------- */
#define CONFIG_TIMEOUT 300                // Setup Portal timeout
#define CONFIG_KEEPALIVE 57               // "keepAlive" configuration parameter default
#define CONFIG_MQTT_PORT 1883             // "mqttport" configuration parameter default
#define CONFIG_MQTT_RETAIN true           // "retain" configuration parameter default
#define CONFIG_MQTT_BROKER ""             // "mqttbroker" configuration parameter default
#define CONFIG_MQTT_USER ""               // "mqttuser" configuration parameter default
#define CONFIG_MQTT_PASS ""               // "mqttpass" configuration parameter default
#define CONFIG_MQTT_NAMESPACE "namespc"   // "namespc" configuration parameter default
#define CONFIG_MQTT_KEY ""                // "mqttkey" configuration parameter default
#define CONFIG_LGT_DIMM true              // "LgtDimm" configuration parameter default
#define CONFIG_LGT_TRNS true              // "LgtTrns" configuration parameter default
#define CONFIG_LED_INST_ON 100            // "LedInstOn" configuration parameter default
#define CONFIG_LED_INST_OFF 25            // "LedInstOff" configuration parameter default
#define CONFIG_LED_DEFAULT true           // "LedDefault" configuration parameter default
#define CONFIG_DIMMING_TIME 2500          // "dimmTime" configuration parameter default
#define CONFIG_EDGE_TIME 800              // "edgeTime" configuration parameter default
#define CONFIG_TRANSITION_ON 0            // "transitionOn" configuration parameter default
#define CONFIG_TRANSITION_OFF 0           // "transitionOff" configuration parameter default
#define CONFIG_MIN_POW 4                  // "minPow" configuration parameter default
#define CONFIG_MIN_TU_BRG 12              // "iMinTUB" configuration parameter default
#define CONFIG_BRIGHTNESS 100             // "brightness" configuration parameter default


/* -------------------------------------------------------------------------------------------- 
   Double Reset
   -------------------------------------------------------------------------------------------- */
// Time between resets to detect a double reset
#define DRD_TIMEOUT                       1.5

// Hardware address
#define DRD_ADDRESS                       0x00


/* -------------------------------------------------------------------------------------------- 
    Direct OTA Updates
   -------------------------------------------------------------------------------------------- */
// OTA Port
//#define OTA_AR_PORT 8266

// MD5 Hash for secure OTA Arduino Updates
//#define OTA_AR_HASH "266ba2d990fc2ff1ef34c571e4ea49de"

// Password for secure OTA Arduino Updates (not recommended)
//#define OTA_AR_PASS "myOtaPass"


/* -------------------------------------------------------------------------------------------- 
    OTA through HTTP Server (Overrides Direct OTA Updates)
   -------------------------------------------------------------------------------------------- */
// Define the next 4 parameters to update from an HTTP Server
#define OTA_HTTP_SERVER                   "your_server_name"
#define OTA_HTTP_PORT                     80
#define OTA_SCRIPT_NAME                   "your_path/updatedimmer.php"
                  
// Another option is to define the Http server in a single line
//#define OTA_HTTP_URL                    "http://your_server_name/your_path/updatedimmer.php"


/* -------------------------------------------------------------------------------------------- 
    Debug
   -------------------------------------------------------------------------------------------- */
// Enable debug messages to serial port
#define DEBUG_MODE

// Serial port speed
#define SERIAL_SPEED                      74880


//              ^            ^            ^            ^            ^ 
//
// Sketch configuration ends here
//
//////////////////////////////////////////////////////////////////////////////////////////////////
//////////////////////////////////////////////////////////////////////////////////////////////////
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
void loop () {
  /* ------------------------------------------------------------------------------
     Handle OTA updates
     ------------------------------------------------------------------------------ */
  #if defined(OTA_UPDATES) && !defined(OTA_HTTP)
    if (otaEnabled) {
      ArduinoOTA.handle();
    }
  #endif

  /* ------------------------------------------------------------------------------
     Validate network connections
     ------------------------------------------------------------------------------ */
  unsigned long cTmr = millis();
  if (netCheck()) {
    // Process pending messages
    if ((unsigned long)(cTmr - pubMillis) > MQTT_BUFFER_TMR) {
      // Process pending messages
      mqttPublishBuffer();
      pubMillis = cTmr;
    }
    // Refresh net check timer
    netMillis = cTmr;
    #ifdef COLLECT_STATS
      // Reset net fail second couter
      statNoNet = 0;
    #endif
  } else {
    // Attemp to re-establish network conections
    netConnect();
    // Refresh the publish timer
    pubMillis = cTmr;
  }
  
  /* ------------------------------------------------------------------------------
     Keep track of running time
     ------------------------------------------------------------------------------ */
  systemTimer();
  
  /* ------------------------------------------------------------------------------
     Set action for buttons depending on status
     ------------------------------------------------------------------------------ */
  int btn;
  #ifdef DBL_CLICK
    char pyl[4];
  #endif
  for (int i = 0; i < INSTANCE_NUM; i++) {
    btn = getButtonStatus(i);
    // Button down
    if (btn == 1) {
      // Any user activity deactivates the GoLive sequence
      goLiveOff(); 
    }
    // Button UP = Toggle instance status
    else if (btn == 2) {
      #ifdef SWITCH_MODE
        setInstanceState(i, 2, true, false);
      #endif
      #ifdef DIMMER_MODE
        setInstanceState(i, 2, -1, -1, true, false);
      #endif
      #ifdef COLLECT_STATS
        ++statBtnCnt;
      #endif
    }
    // Button UP after long press = toggle switch or report light status
    else if (btn == 3 || btn == 4) {
      #ifdef SWITCH_MODE
        setInstanceState(i, 3, true, false);
      #endif
      #ifdef DIMMER_MODE
        if (dconfig.iDimm[i]) {
          setInstanceState(i, 3, -1, 0, true, false);
        } else {
          setInstanceState(i, 2, -1, -1, true, false);
        }
      #endif
      #ifdef COLLECT_STATS
        ++statBtnCnt;
      #endif
    }
    #ifdef DIMMER_MODE
      // Button Repeat with dimmer enabled
      else if (dconfig.iDimm[i] && btn == 5) {
        setInstanceState(i, 1, -2, 0, false, false);
      }
    #endif
    #ifdef DBL_CLICK
      else if(btn == 6) {
        #ifdef DEBUG_MODE
          writeDebug("Double-click button", 1);
        #endif
        sprintf(pyl, "dc%d", (i + 1));
        mqttPublish(2, i, pyl, false);
        #ifdef COLLECT_STATS
          ++statBtnCnt;
        #endif
      }
      else if(btn == 7) {
        #ifdef DEBUG_MODE
          writeDebug("Triple-click button", 1);
        #endif
        sprintf(pyl, "tc%d", (i + 1));
        mqttPublish(2, i, pyl, false);
        #ifdef COLLECT_STATS
          ++statBtnCnt;
        #endif
      }
    #endif
    #ifdef MULT_CLICK
      else if(btn == 8) {
        #ifdef DEBUG_MODE
          writeDebug("Multi-click button", 1);
        #endif
        #ifdef COLLECT_STATS
          ++statBtnCnt;
        #endif
        goToSetupMode();
      }
    #endif
  }
  ////////////////////////////////////////////////////////////////////////////////
  // Set the LED indicator brightness
  ////////////////////////////////////////////////////////////////////////////////
  handleLed();

  #ifdef COLLECT_STATS
    // Count the number of times the loop is executed
    ++statLoopCnt;
  #endif
}

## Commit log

2023-06-20 Release 0.8.07
    - Correct MQTT debug information.
    - Isolate Debug variables.
    - Improve WiFi reconnect retry.
    - Smooth variable frequency.
    - Fixed issue with flickering when 2 lights are turned on.
    [DimmerEsp_Current.ino]
2023-08-14 Release 0.8.08
    - Fix issue with reporting IP address in "getInfo" MQTT event.
    - Change the saved AC Freq read process, to prevent potential infinite boot loop.
    - Improve WiFi/MQTT re-connect sequence.
    [DimmerEsp_Current.ino]
2023-08-14 Create update.php
    Sample program to locally update the dimmer release Over the Air
